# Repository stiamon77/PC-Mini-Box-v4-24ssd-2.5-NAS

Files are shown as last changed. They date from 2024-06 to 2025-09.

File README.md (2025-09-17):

# Mini PC Box v4

## [Lend your support to our projects](https://taplink.cc/aqstqa)

**Industrial and interface design: [Liberiam (Mary Timofeeva)](https://www.linkedin.com/in/marija-timofeeva-184484382/)**

[**New version with touch screen V5**](https://github.com/stiamon77/AQSTQA-PC-BOX-S-Mini-ITX)

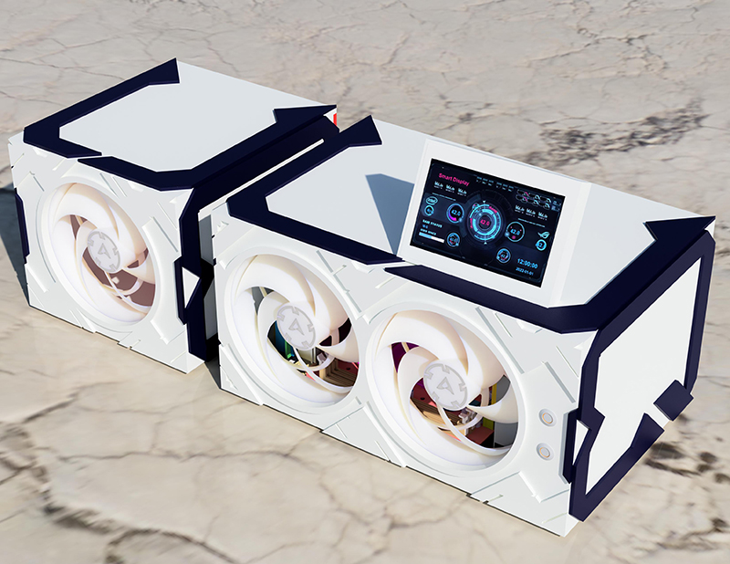
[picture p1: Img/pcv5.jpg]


This is a very compact computer case that I made for my NAS on SSD 2.5 drives with a RAID controller.
The model was created for laser cutting from sheet material (I used acrylic of different colors, white 9016, black RAL 9005 and ultramarine RAL 5002).
The model was created in Fusion 360.

**Version V4**

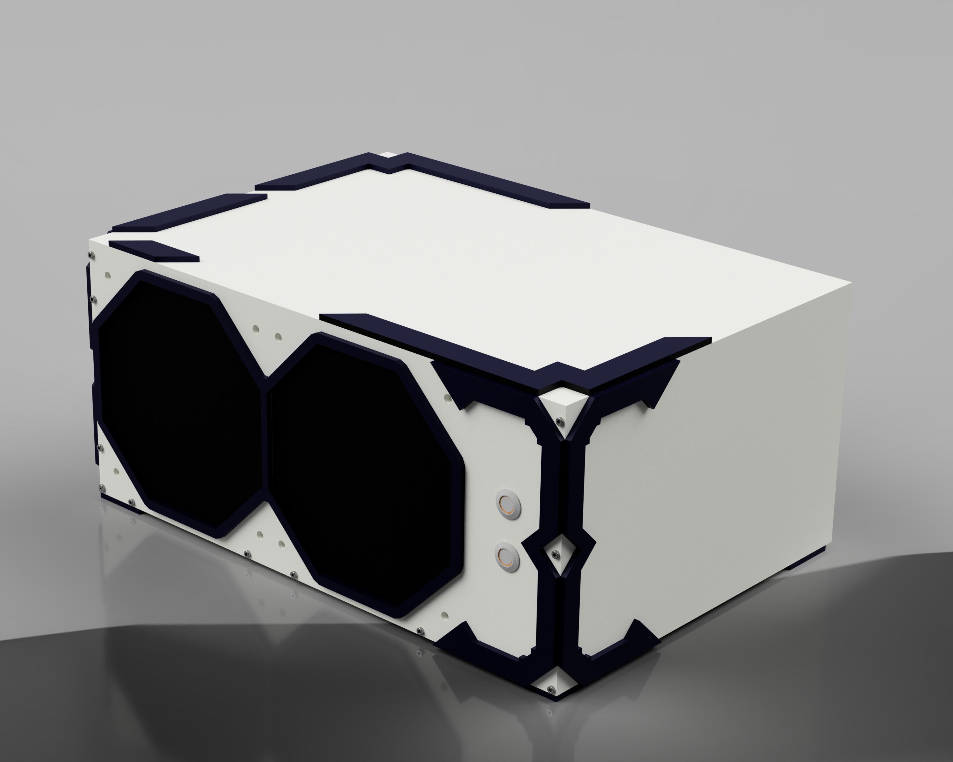
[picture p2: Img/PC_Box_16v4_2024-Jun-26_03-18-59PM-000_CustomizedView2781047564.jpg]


**3D model Fusion 360** 

[**part1**](https://github.com/stiamon77/PC-Mini-Box-v4-24ssd-2.5-NAS/blob/main/Model/PC%20Box%2016v4%20v17%20(F3Z).part1.rar)
[**part2**](https://github.com/stiamon77/PC-Mini-Box-v4-24ssd-2.5-NAS/blob/main/Model/PC%20Box%2016v4%20v17%20(F3Z).part2.rar)
[**part3**](https://github.com/stiamon77/PC-Mini-Box-v4-24ssd-2.5-NAS/blob/main/Model/PC%20Box%2016v4%20v17%20(F3Z).part3.rar)

[** **Laser cutting files** **](https://github.com/stiamon77/PC-Mini-Box-v4-24ssd-2.5-NAS/tree/main/For%20laser%20cutting)

The folder contains two Corel Draw files and each part separately in dxf format. For laser cutting I used 5mm and 3mm acrylic. You can use any solid sheet plastic in these sizes.
You can order laser cutting according to these drawings in your city from any company that provides these services. It is not expensive )

**Computer hardware and case parts**

1. Any mini-ITX motherboard will do. Check the height of the cooling system. And at least one PCI-Express x16 for the RAID controller. I used the board ASRock J4005B-ITX
2. [**RAID controller, I used LSI MegaRAID 9260-8i + LSI bbu08, this is a good and inexpensive controller**](https://s.click.aliexpress.com/e/_mN7rkys)
3. [**Expansion card for 16 drives (HBA Cards), Which will allow you to connect 20 disks to RAID.**](https://s.click.aliexpress.com/e/_oCTe7vc)
4. [**Cables for connecting drives to the RAID controller (Mini SAS 4i SFF8087 36P To 4 SATA) 25cm or 0.5m, 5 items**](https://s.click.aliexpress.com/e/_m0wkBo8)
5. [**Connection cable MegaRAID 9260-8 in HBA Cards (Mini Sas Sff 8087) 0.3m, 1 items**](https://s.click.aliexpress.com/e/_mPbJIv6)
6. [**16x Extender Riser Adapter Card for powering HBA Cards**](https://s.click.aliexpress.com/e/_omNainU)
7. TFX power supply 250-300 watts or more, depends on your motherboard, if it is powerful and you plan to load this computer, then calculate the power of the power supply based on this. I disassembled my power supply and got rid of the metal casing
8. [**Two good 120mm fans**](https://s.click.aliexpress.com/e/_olfPU1C)
9. [**Two buttons with 12mm indication for turning on and restarting the PC. The first button is connected to the power indication, the second to the HDD operation indication on the motherboard**](https://s.click.aliexpress.com/e/_opKHAS2)
10. [**Anti Vibration Silicone Screws PC Fan, for attaching fans to the front cover**](https://s.click.aliexpress.com/e/_mqwq2zE)
11. [**Magnets for attaching the top cover. For this purpose, special holes are provided in the connectors (see 3d model). Need magnets, width 4mm, length 3mm, 8 pieces**](https://s.click.aliexpress.com/e/_okThaLU)
12. [**M2 bolts for fastening the front cover (M2, 10mm, 10 pieces)**](https://s.click.aliexpress.com/e/_mNhPjba), [**color metal**](https://s.click.aliexpress.com/e/_mNhPjba) or [**black**](https://s.click.aliexpress.com/e/_mKz7Iay)
13. [**Hot Melt Thread Knurled (M2, OD 3,2mm, 10 pieces. And M3, OD 5mm, 10 pieces.) They are fused into the plastic to secure the bolts.**](https://s.click.aliexpress.com/e/_EycOUV1)
14. [**Hex Standoff for Motherboard Board. For attaching the motherboard to the bottom of the case. (M3, Dimensions may vary depending on your motherboard, usually 6mm, 10 pieces**](https://s.click.aliexpress.com/e/_oCelR1y)
15. [**Decorative mesh for the front and back of the case.**](https://s.click.aliexpress.com/e/_onzry1C) [**And you may also need dust protection.**](https://s.click.aliexpress.com/e/_okZUZ0w)
16. In order not to clog the case space with a bunch of wires, it is better to make a power cable for SATA drives yourself. It's easy to do, all you need are [**wires 18AWG (yellow, black 2x, red, I had 10 meters to spare)**](https://s.click.aliexpress.com/e/_mqA43wY) and [**connectors (With 180 Cap).**](https://s.click.aliexpress.com/e/_mPAv6ti)
17. You will also need glue for the plastic from which you will make the body. Choose special, good glue.

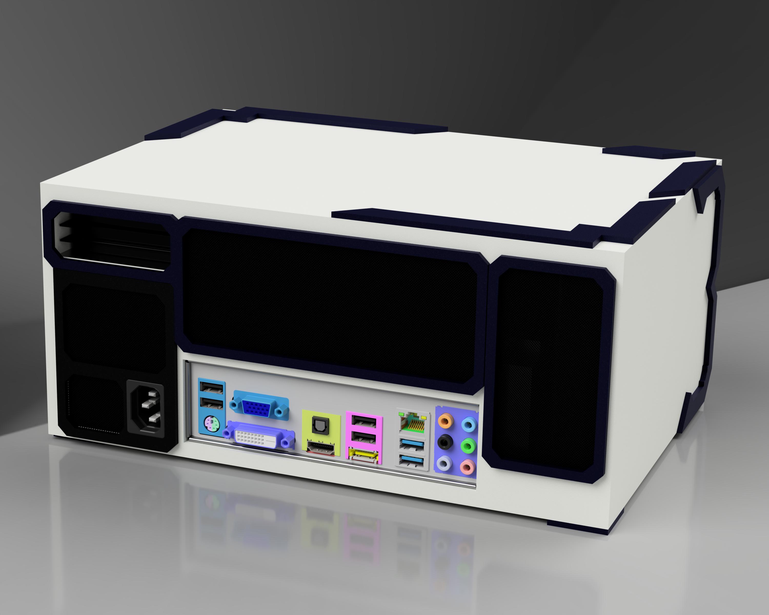
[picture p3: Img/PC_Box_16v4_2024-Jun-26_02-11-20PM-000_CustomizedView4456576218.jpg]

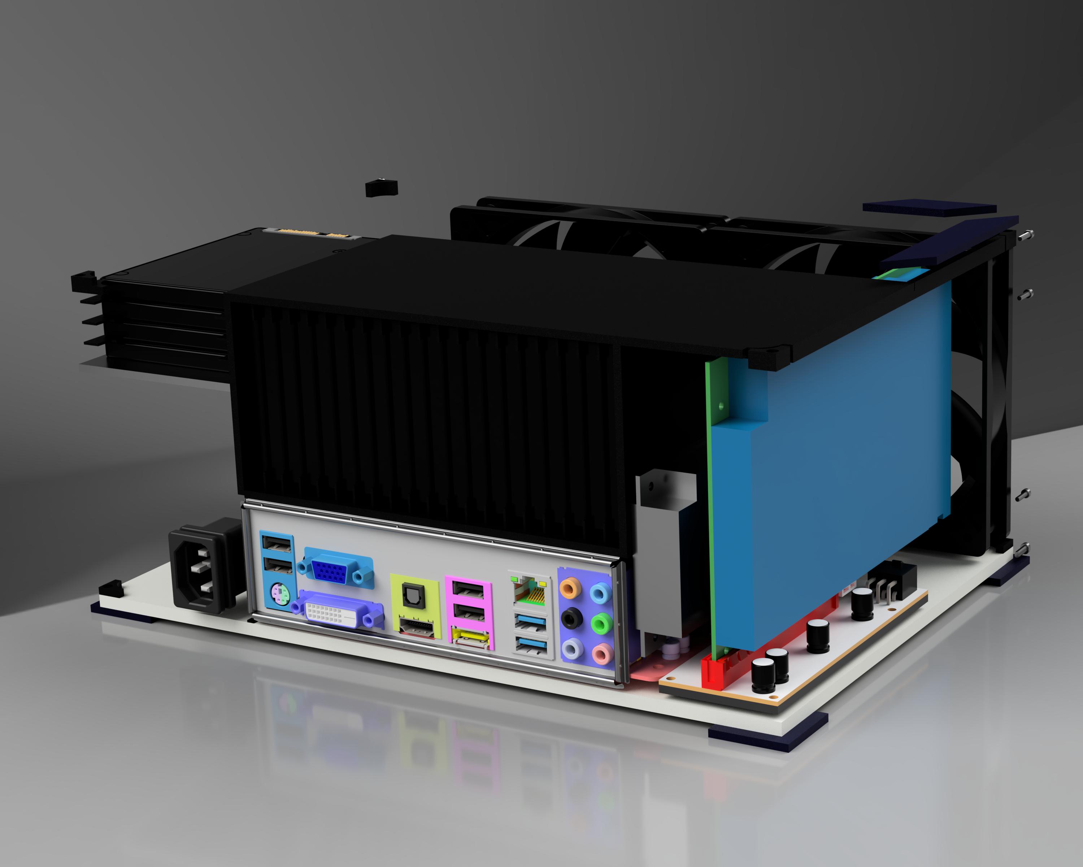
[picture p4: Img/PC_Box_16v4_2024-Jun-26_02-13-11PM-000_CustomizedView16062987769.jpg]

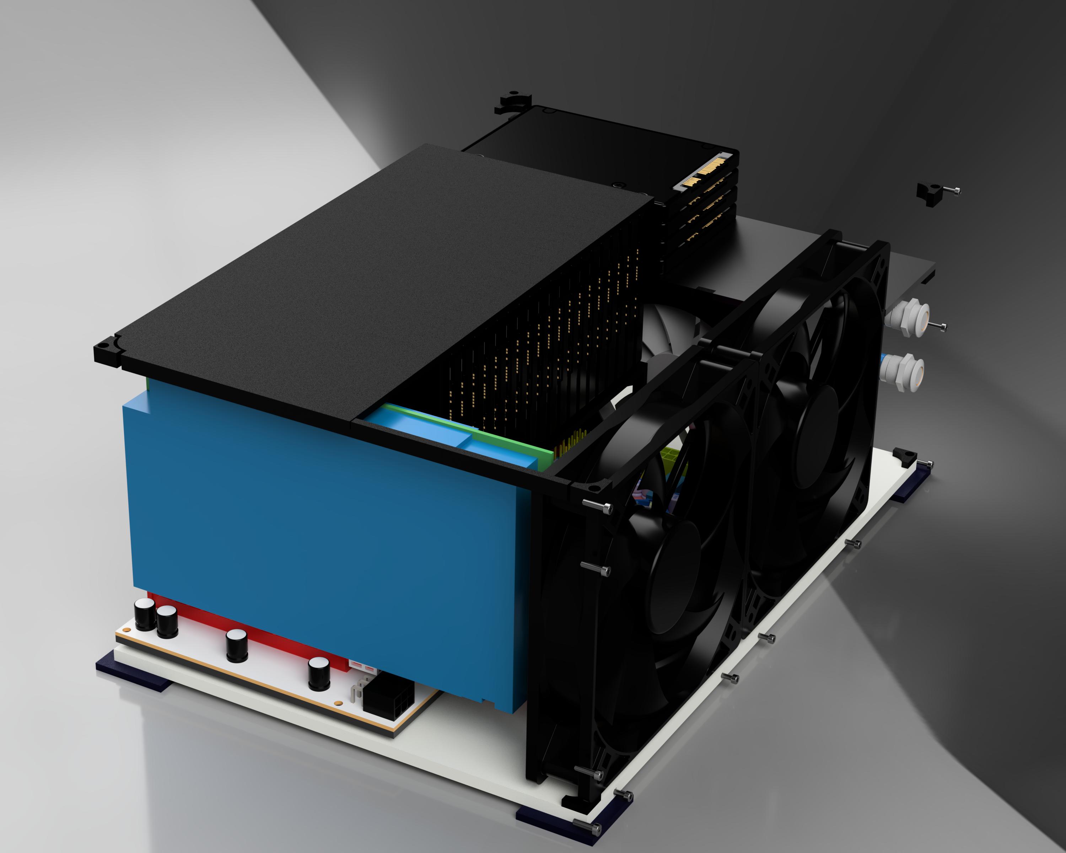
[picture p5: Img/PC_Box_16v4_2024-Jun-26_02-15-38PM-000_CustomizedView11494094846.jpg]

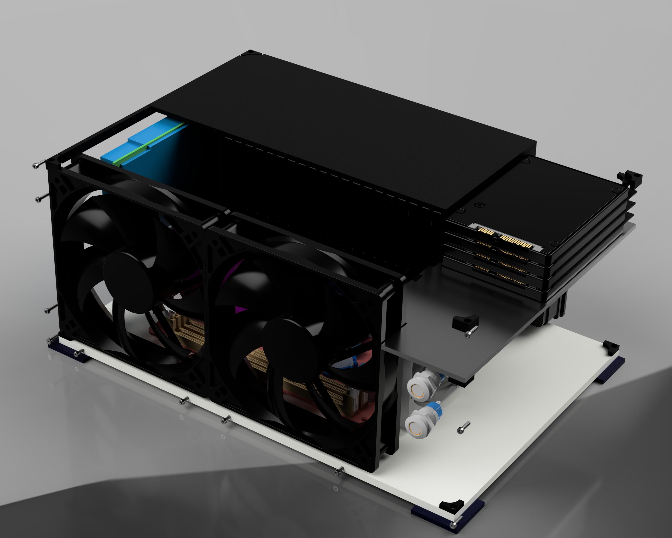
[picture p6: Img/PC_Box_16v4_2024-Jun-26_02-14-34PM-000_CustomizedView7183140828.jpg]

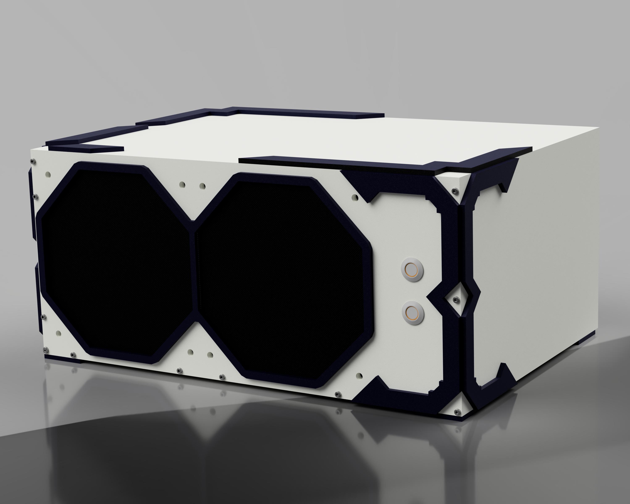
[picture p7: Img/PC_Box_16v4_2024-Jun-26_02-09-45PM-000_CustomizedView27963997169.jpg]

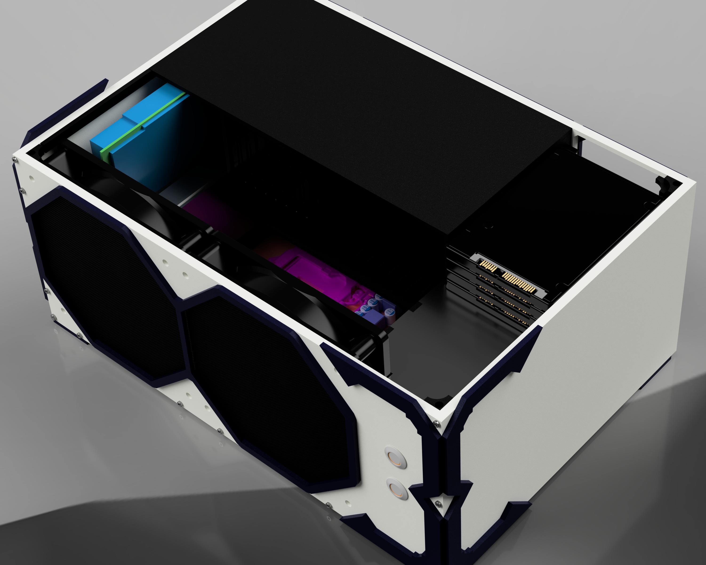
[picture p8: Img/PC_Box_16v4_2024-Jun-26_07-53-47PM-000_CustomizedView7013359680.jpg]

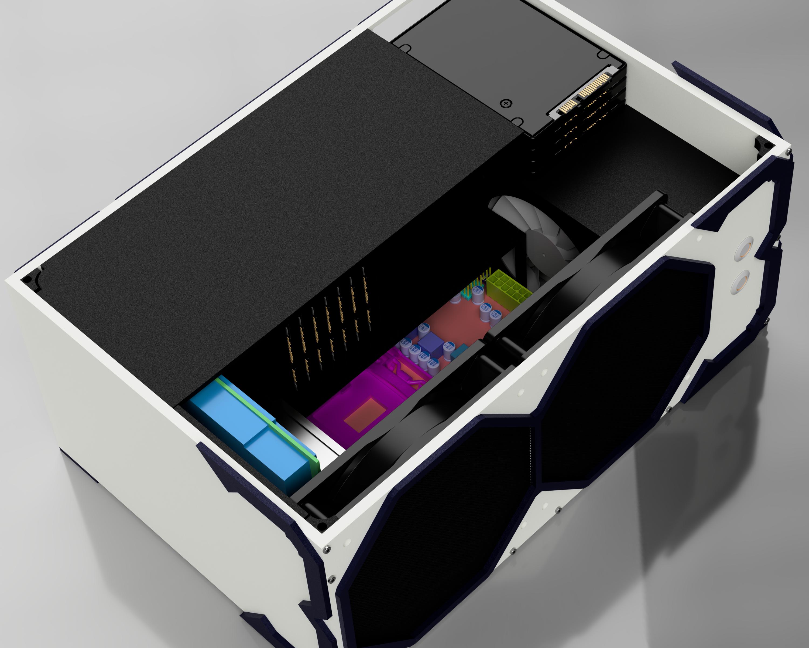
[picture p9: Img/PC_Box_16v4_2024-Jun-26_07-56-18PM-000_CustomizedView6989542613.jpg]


## [Lend your support to our projects](https://taplink.cc/aqstqa)

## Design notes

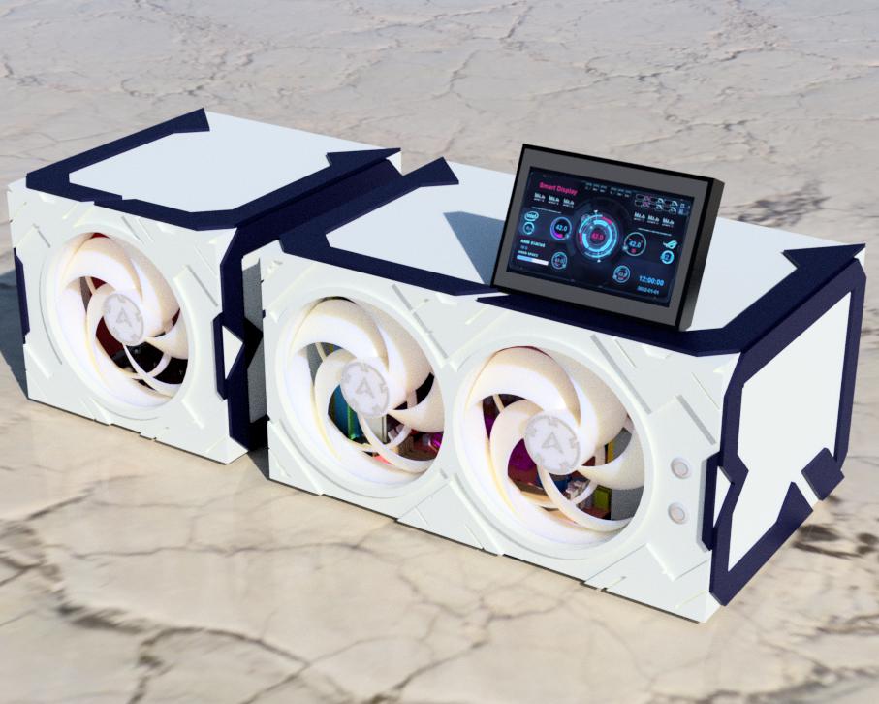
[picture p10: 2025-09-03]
Img/AQSTQA PC BOX S+ Mini-ITX v1 v15.jpg

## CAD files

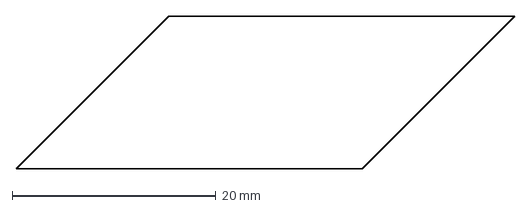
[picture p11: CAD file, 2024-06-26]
For laser cutting/Decorative element 4 3mm.dxf
49.0 x 15.0 mm

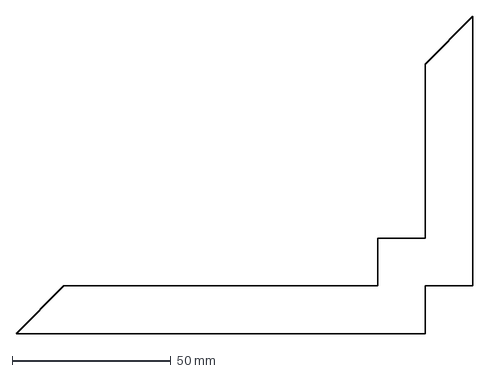
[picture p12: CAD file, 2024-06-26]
For laser cutting/Decorative element 5 3mm.dxf
144.0 x 100.0 mm

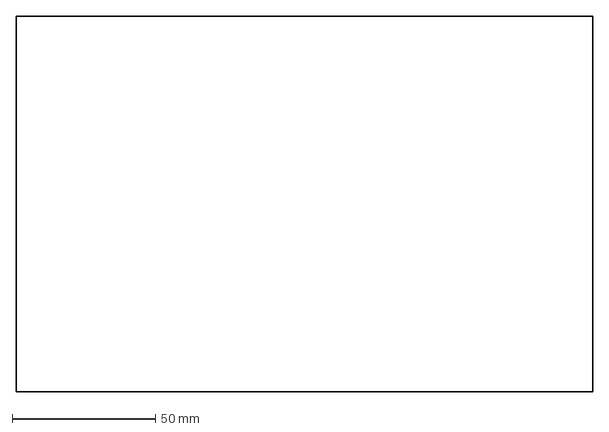
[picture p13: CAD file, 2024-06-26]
For laser cutting/Left panel 5mm.dxf
201.0 x 131.0 mm

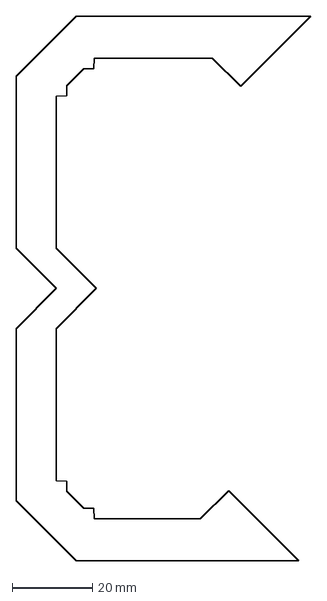
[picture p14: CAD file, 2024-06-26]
For laser cutting/Decorative element 8 3mm.dxf
73.6 x 136.0 mm

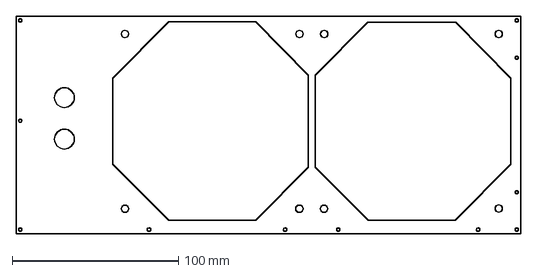
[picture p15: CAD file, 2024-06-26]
For laser cutting/Front panel 5mm.dxf
304.0 x 131.0 mm

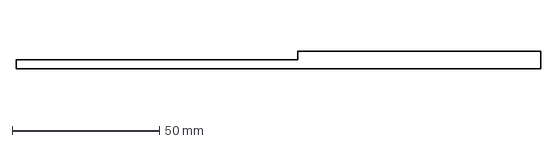
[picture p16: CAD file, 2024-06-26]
For laser cutting/RAID 3 3mm.dxf
177.9 x 6.00 mm

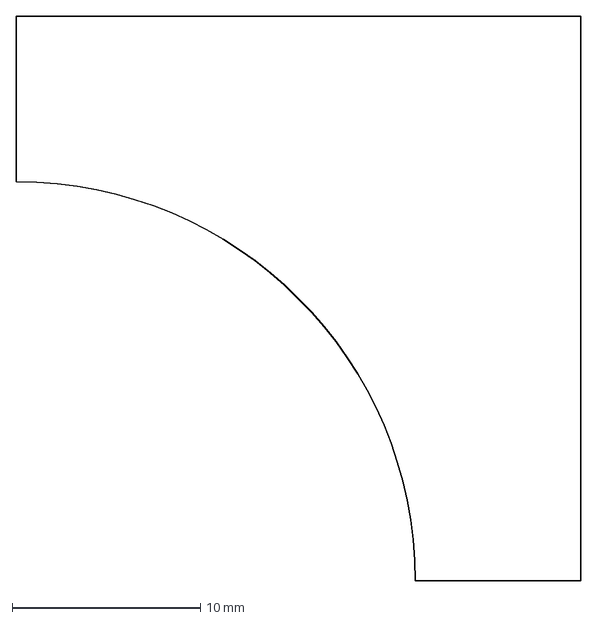
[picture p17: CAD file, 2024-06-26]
For laser cutting/Legs 3mm.dxf
30.0 x 30.0 mm

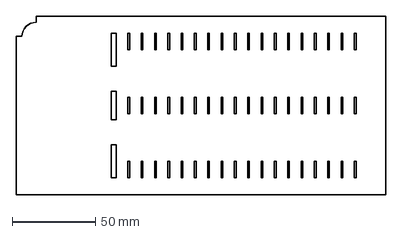
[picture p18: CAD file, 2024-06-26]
For laser cutting/RAID 5 3mm.dxf
222.0 x 107.0 mm

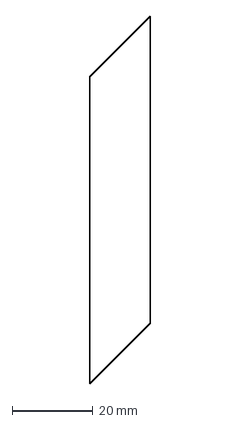
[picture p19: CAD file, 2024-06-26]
For laser cutting/Decorative element 3 3mm.dxf
15.0 x 90.9 mm

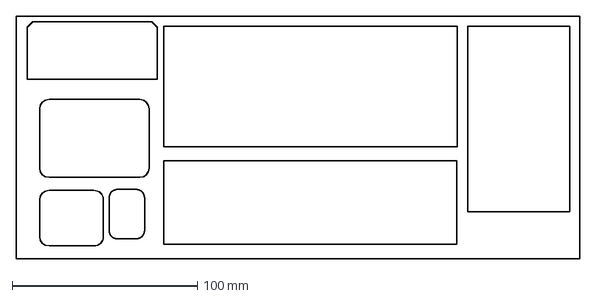
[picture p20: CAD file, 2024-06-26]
For laser cutting/Back panel 5mm.dxf
304.0 x 131.0 mm

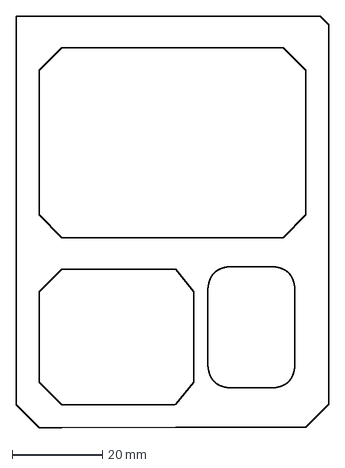
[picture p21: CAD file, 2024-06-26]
For laser cutting/Decorative element 10 3mm.dxf
69.0 x 90.9 mm

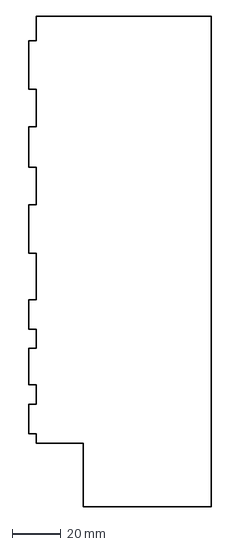
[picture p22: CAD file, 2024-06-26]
For laser cutting/RAID 6 3mm.dxf
75.0 x 201.0 mm

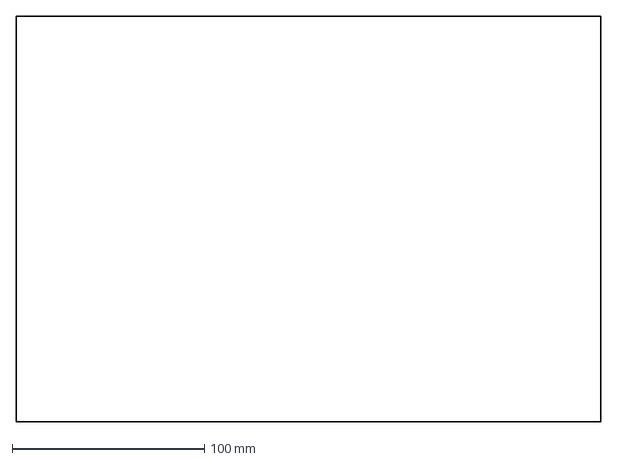
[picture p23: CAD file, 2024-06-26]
For laser cutting/Top cover 5mm.dxf
304.0 x 211.0 mm

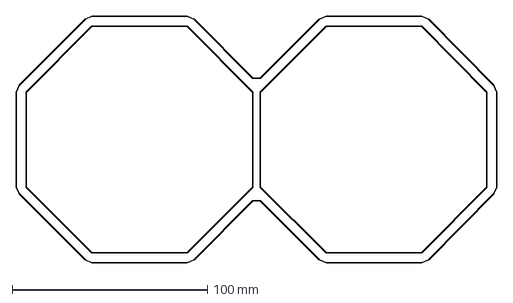
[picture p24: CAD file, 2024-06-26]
For laser cutting/Decorative element 1 3mm.dxf
246.0 x 126.0 mm

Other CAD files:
For laser cutting/RAID 2 3mm.dxf
For laser cutting/Bottom cover 5mm.dxf
For laser cutting/Connector 3mm.dxf
For laser cutting/Decorative element 2-1 3mm.dxf
For laser cutting/Decorative element 2-2 3mm.dxf
For laser cutting/RAID 1 3mm.dxf
For laser cutting/RAID 4 3mm.dxf
